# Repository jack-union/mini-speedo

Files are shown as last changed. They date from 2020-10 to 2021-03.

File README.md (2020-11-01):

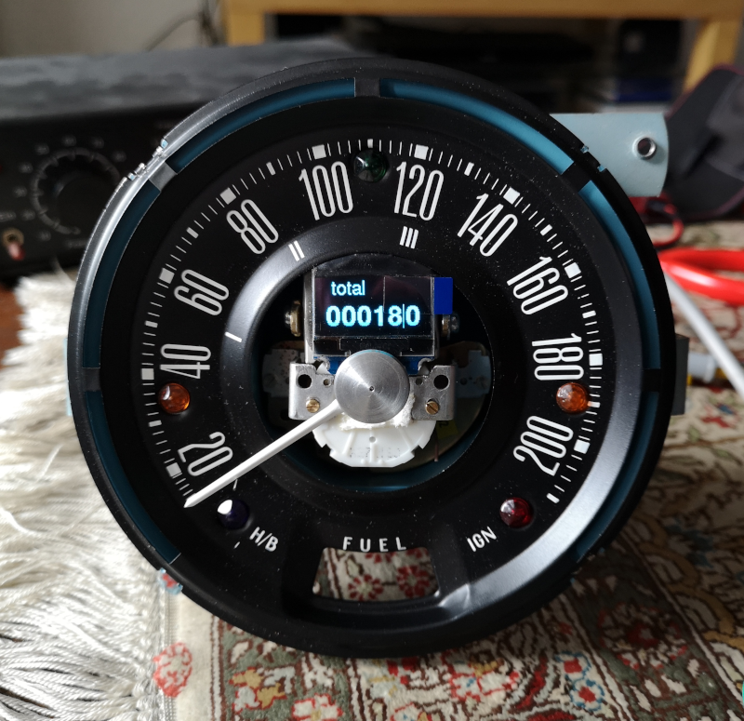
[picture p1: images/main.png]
mainimage


# mini-speedo
Electronic Speedo for classic minis

Using an Arduino Nano v3, a SSD1306 0,96" 128x64 display and a GM X27.168 stepper motor.

Featuring a multifunction display for:
* total distance
* trip distance
* digital speed
* lambda (AFR)
* oil temperature
* oil pressure
* voltage
* water temperature
* external temperature
* rpm

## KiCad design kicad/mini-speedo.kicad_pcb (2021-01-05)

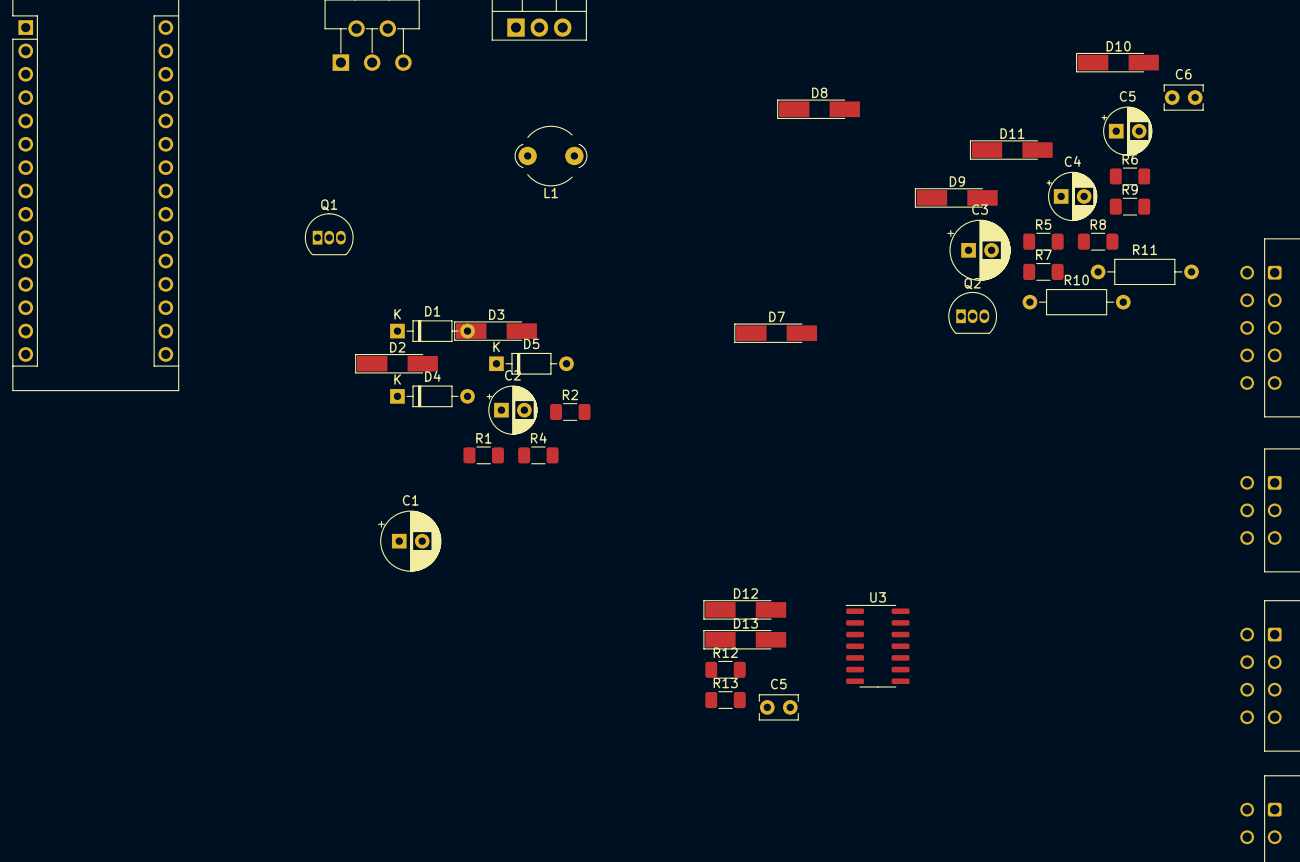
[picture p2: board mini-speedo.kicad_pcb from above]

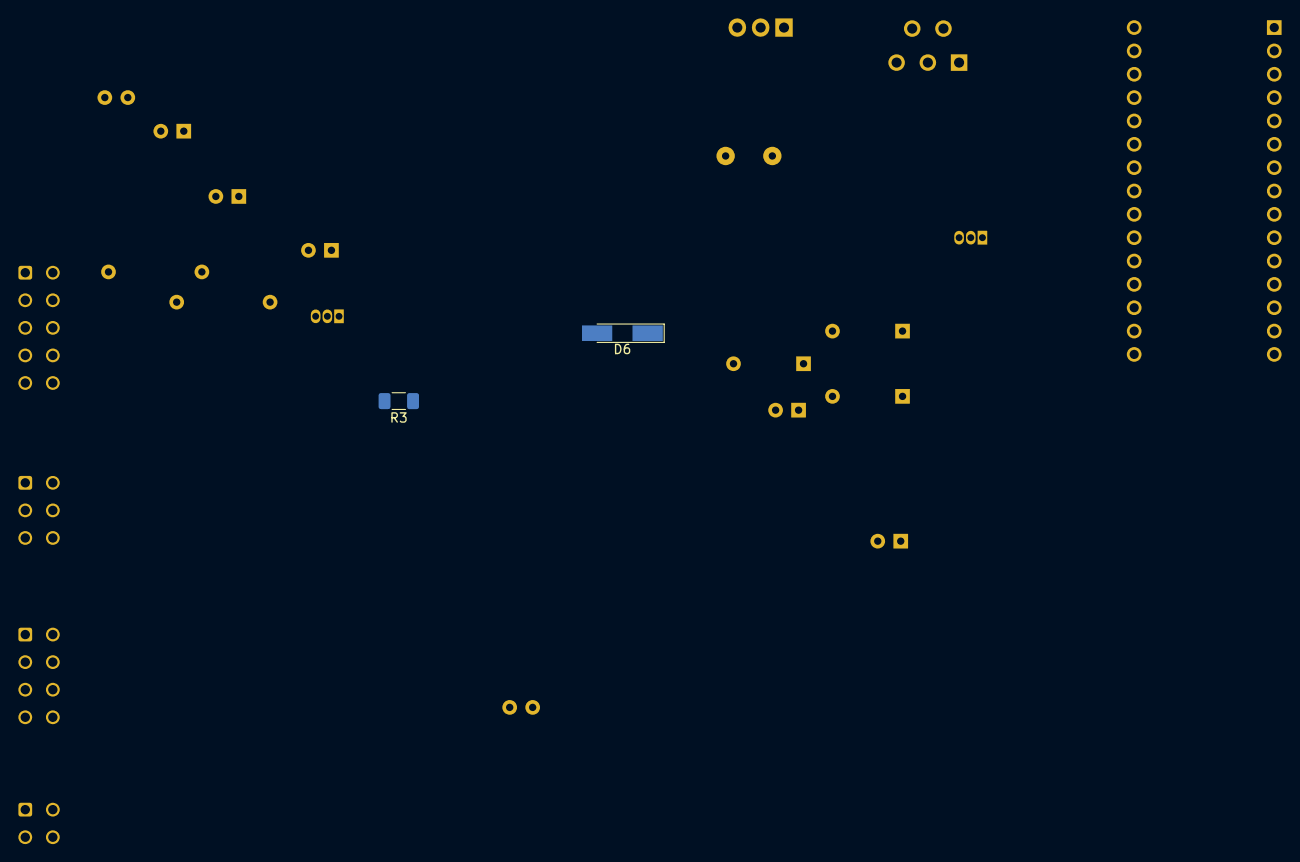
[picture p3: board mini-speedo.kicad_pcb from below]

Board: 2 copper layers, 44 parts (2 on the bottom side), 34 nets, no tracks yet.

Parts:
A1: Arduino; Arduino_Nano
C1, C3: 47uF; CP_Radial_D6.3mm_P2.50mm
C2, C4: 33uF; CP_Radial_D5.0mm_P2.50mm
C5: 10uF; CP_Radial_D5.0mm_P2.50mm
C5#2: 10nF; C_Rect_L4.0mm_W2.5mm_P2.50mm
C6: 33nF; C_Rect_L4.0mm_W2.5mm_P2.50mm
D1: D_Schottky; D_DO-35_SOD27_P7.62mm_Horizontal
D2, D3, D6, D7, D8, D9, D10, D11, D12, D13: 4.7V; D_MiniMELF_Handsoldering
D4, D5: 1N4148; D_DO-35_SOD27_P7.62mm_Horizontal
J1: Conn_01x06; Molex_Micro-Fit_3.0_43045-0600_2x03_P3.00mm_Horizontal
J2: Conn_01x08; Molex_Micro-Fit_3.0_43045-0800_2x04_P3.00mm_Horizontal
J3: Conn_01x10; Molex_Micro-Fit_3.0_43045-1000_2x05_P3.00mm_Horizontal
J4: Conn_01x04; Molex_Micro-Fit_3.0_43045-0400_2x02_P3.00mm_Horizontal
L1: 33uH; LairdTech_28C0236-0JW-10
Q1, Q2: BC546; TO-92_Inline
R1, R2, R3, R4, R6, R7, R8, R13: 10k; R_1206_3216Metric_Pad1.30x1.75mm_HandSolder
R5: 30k; R_1206_3216Metric_Pad1.30x1.75mm_HandSolder
R9: 1k; R_1206_3216Metric_Pad1.30x1.75mm_HandSolder
R10: 100; R_Axial_DIN0207_L6.3mm_D2.5mm_P10.16mm_Horizontal
R11: 470; R_Axial_DIN0207_L6.3mm_D2.5mm_P10.16mm_Horizontal
R12: 15k; R_1206_3216Metric_Pad1.30x1.75mm_HandSolder
U1: LM2596T-5; TO-220-5_P3.4x3.7mm_StaggerOdd_Lead3.8mm_Vertical
U2: LM7810_TO220; TO-220-3_Vertical
U3: 74HC14; SO-14_3.9x8.65mm_P1.27mm

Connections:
GND: A1.4, A1.29, C1.2, C2.2, C3.2, C4.2, C5.2, C5#2.2, C6.2, D1.2, D2.2, D3.2, D6.2, D7.2, D8.2, D9.2, D10.2, D11.2, D13.2, J1.6, J2.8, J3.2, J4.4, Q1.3, Q2.3, R6.1, R7.1, R13.1, U1.3, U2.2, U3.7
unnamed: A1.5, D8.1, R9.1
unnamed: A1.6, U3.2
unnamed: A1.7, J2.1
unnamed: A1.8, J2.2
unnamed: A1.9, J2.3
unnamed: A1.10, J2.4
unnamed: A1.13, D4.2
unnamed: A1.14, D2.1, R4.1
unnamed: A1.15, D5.1
unnamed: A1.16, R3.1
unnamed: A1.19, J3.3
unnamed: A1.20, D11.1, J3.5, R11.1
unnamed: A1.21, D10.1, J3.6, R10.1
unnamed: A1.22, D9.1, J3.7
unnamed: A1.23, J2.6
unnamed: A1.24, J2.7
unnamed: A1.25, C6.1, D7.1, R7.2, R8.1
unnamed: A1.26, C5.1, D6.1, R5.1, R6.2
unnamed: A1.27, C2.1, D12.1, J2.5, J3.1, L1.1, R10.2, R11.2, U1.4, U3.14
unnamed: C1.1, J1.1, U1.1
unnamed: C3.1, J1.2, J4.2, R1.2, R4.2, R5.2, U2.1
unnamed: C4.1, J1.3, U2.3
unnamed: C5#2.1, D12.2, D13.1, R12.1, R13.2
unnamed: D1.1, L1.2, U1.2
unnamed: D3.1, D5.2, R2.1, U1.5
unnamed: D4.1, J1.4
unnamed: J1.5, Q2.1
unnamed: J3.4, R8.2
unnamed: J4.1, R12.2
unnamed: J4.3, R9.2
unnamed: Q1.1, R2.2
unnamed: Q1.2, R1.1
unnamed: Q2.2, R3.2

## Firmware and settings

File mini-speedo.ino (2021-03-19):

/*
  Speedo with multifunction display

  Discussed here:
  https://www.mini-forum.de/forum/thread/95593-elektronischer-mitteltacho/

  Inspired by: https://retromini.weebly.com/blog/arduino-speedometer#

  Complete rewrite, though.

  Uses an Arduino Nano, a X27 stepper motor and a 0,96" OLED SSD1306 display

  jack union, 2020.

*/

#define MINI_SPEEDO_VERSION "Speedo v0.7"

//----Libraries to Include--------
#include <Arduino.h>
#include <Wire.h>
// edited in clib/u8g2.h
//#define U8G2_WITH_CLIP_WINDOW_SUPPORT
//#define U8G2_WITH_FONT_ROTATION
//#define U8G2_WITH_UNICODE
#include "SwitecX25.h"
#include <AltSoftSerial.h>
#include <EEPROMex.h>
#include <OneWire.h>
#include <U8g2lib.h>
#include <avr/wdt.h>
#define REQUIRESNEW false
#define REQUIRESALARMS false
#include <DallasTemperature.h>
//----End Libraries--------------

//----Define PIN Settings----------
#define INPUT_SPEED 2   // Interruptable PIN on Nano
#define INPUT_RPM 3     // Interruptable PIN on Nano
#define STEPPIN_1 4     // back view top right pin
#define STEPPIN_2 5     // back view bottom right pin
#define STEPPIN_3 6     // back view bottom left pin
#define STEPPIN_4 7     // back view top left pin
#define SERIAL_RX 8     // D8 lambda digital serial input
#define SERIAL_TX 9     // D9 lambda digital serial input
#define INPUT_BUTTON 10 // brake light test button
#define INPUT_POWER 11  // Power sense pin
#define OUTPUT_POWER 12 // Power off pin
#define OUTPUT_WARN 13  // D13 warn light out

#define INPUT_OUTSIDETEMP A0
#define INPUT_OILTEMP A1
#define INPUT_OILPRESS A2
#define INPUT_LAMBDA A3
// A4: SDA
// A5: SCL
#define INPUT_WATERTEMP A6
#define INPUT_VOLTAGE A7
//----End Define PIN Settings------

//----Define Lambda sensor input----
//#define LAMBDA_DIGITAL true //RX and TX serial pins
#define LAMBDA_DIGITAL false // analog 5V input
//----End Define Lambda sensor input----

//----Define warning limits----
#define WARN_MAX_OILTEMP 120   // 120° Celsius
#define WARN_MIN_OILPRESS 100  // 1 bar pressure
#define WARN_MIN_VOLTAGE 118   // 11.8 Volts
#define WARN_MAX_VOLTAGE 154   // 15.4 Volts
#define WARN_MAX_WATERTEMP 100 // 100° Celsius
#define WARN_MIN_OUTSIDETEMP 2 // 2° Celsius
//----End Define warning limits----

//----Define OLED Display Settings----
#define SCREEN_WIDTH 128 // OLED display width, in pixels
#define SCREEN_HEIGHT 64 // OLED display height, in pixels
//-----End OLED Display Settings------

//----Define other constants-------
#define SPEED_IMP_PER_REV 6 // impulses per revolution
#define IMP_PER_KM 800      // "Wegstrecke", impulses per 1000m
#define RPM_IMP_PER_REV 2   // SPI/Distributor, set to 1 for MPI
#define UPDATE_INTERVAL 100 // milliseconds speedo update rate
#define TEMP_EVERY_LOOPS 10 // every 10 loops update Dallas temperature sensor
//----End Define other constants---

//----Define sensor constants-------
#define ANALOGSAMPLES 5
#define MINITEMP_T0 303     // 303 Kelvin = 30° Celsius
#define MINITEMP_R0 833     // 833 Ohm at 303 Kelvin
#define MINITEMP_B 3540     // beta constant for Steinhart Hart
#define RACIMEXTEMP_T0 318  // 318 Kelvin = 45° Celsius
#define RACIMEXTEMP_R0 1240 // 1240 Ohm at 318 Kelvin
#define RACIMEXTEMP_B 3850  // beta constant for Steinhart Hart
#define OILTEMP_PULLUP 470  // 470 Ohm to 5V
#define WATERTEMP_PULLUP 61 // Resistance of water temp instrument
#define OILPRESS_PULLUP 100 // 100 Ohm to 5V
#define NODATA 65535        // max uint16 when no data
#define TEMPTOOHIGH 65534   // max uint16 -1 when reading too high
//----End Define sensor constants---

//----Stepper settings and object----
// standard X25.168 range 315 degrees at 1/3 degree steps
#define STEPS 248 * 3
// speedo type
#define SPEEDO_RANGE 210 // cooper with 210kph full range
#define SWEEP_AT_START 1
//----End Stepper settings and object----

//----Display modes----
#define TRIP 0
#define SPEED 1
#define LAMBDA 2
#define OIL_TEMP 3
#define OIL_PRESS 4
#define WATER_TEMP 5
#define VOLT 6
#define OUTSIDE 7
#define RPM 8
#define MINI 9

#define MODEMAX 9
//----End Display modes----

//----Display mode names----
const char *displayNames[] = {
    "trip",  "speed", "lambda",  "oil temp", "oil press",
    "water", "volt",  "outside", "rpm",
    "" // no text in logo mode
};
//----End Display mode names----

//----Define Display settings----
#define X_OFFSET 10
//----End Define Display settings----

//----EERPOM positions----
#define EE_TOKEN_POS 0
#define EE_TOKEN_PATTERN 170 // 10101010
#define EE_TOTAL_POS 1
#define EE_TRIP_POS 5
//----End EERPOM positions----

//----Objects----
// 1,3" SH1106 display
// U8G2_SH1106_128X64_NONAME_2_HW_I2C display(U8G2_R0);
// 0,96" SSD1306 display
U8G2_SSD1306_128X64_NONAME_2_HW_I2C bigDisplay(U8G2_R2);
// 0,96" SSD1306 additional display
U8G2_SSD1306_128X64_NONAME_2_HW_I2C smallDisplay(U8G2_R0);

// create the motor object with the maximum steps allowed
SwitecX25 stepper(STEPS, STEPPIN_1, STEPPIN_2, STEPPIN_3, STEPPIN_4);

// Serial input port
AltSoftSerial altSerial;

// External temperature
OneWire oneWire(INPUT_OUTSIDETEMP);
DallasTemperature outsideSensor(&oneWire);
DeviceAddress dallasDeviceAddress;
//----End Objects----

//-----Variables----------------------
uint32_t total = 0;       // total distance in decimeters
uint32_t trip = 0;        // trip distance in decimeters
uint16_t speed = 0;       // speed in kph
uint16_t lambda = 0;      // lambda factor *100
uint16_t oiltemp = 0;     // temperature in °C
uint16_t oilpress = 0;    // oil pressure in bar *100
uint16_t voltage = 0;     // main voltage in volt *10
uint16_t watertemp = 0;   // temperature in °C
uint16_t outsidetemp = 0; // temperature in °C *10
uint16_t rpm = 0;         // revolutions per minute

bool warningOiltemp = false;
bool warningOilpress = true; // probably no oil pressure at startup
bool warningVoltage = false;
bool warningWatertemp = false;
bool warningOutsidetemp = true; // no real startvalue for TEMP_EVERY_LOOPS

#define ROLLOVER 1000000000 // 100000km in decimeter
byte displayMode = TRIP;    // Startup setting
bool buttonState = HIGH;
bool buttonBeforeState = HIGH;
unsigned long timePressed = 0;
unsigned long displayUpdatedAt = 0;
bool displayChanged = false;
byte loops = 0;

#define ZEROTIME 1000 // no new interrupt pulses for max ms
volatile unsigned long rpmCount = 0;
volatile unsigned long rpmEvent = 0;
unsigned long rpmLastEvent = 0;
volatile unsigned long speedCount = 0;
volatile unsigned long speedEvent = 0;
unsigned long speedLastEvent = 0;

//----End Variables-------------------

//-----Start-up code run once---------
void setup(void) {
  MCUSR = 0;     // clear status register
  wdt_disable(); // watchdog disable

  Serial.begin(115200);
  altSerial.begin(115200);
  Serial.println(F(MINI_SPEEDO_VERSION));

  pinMode(INPUT_SPEED, INPUT_PULLUP);
  pinMode(INPUT_RPM, INPUT_PULLUP);
  pinMode(INPUT_BUTTON, INPUT_PULLUP);
  pinMode(INPUT_POWER, INPUT); // power sense pin
  pinMode(OUTPUT_POWER, OUTPUT);
  digitalWrite(OUTPUT_POWER, LOW); // power on
  pinMode(OUTPUT_WARN, OUTPUT);
  digitalWrite(OUTPUT_WARN, LOW); // warning off

  initOutsideSensor();
  initDisplays();
  delay(1000);
  reset_stepper();

  EEPROM.setMemPool(0, EEPROMSizeNano); // set memory size
  load_from_eeprom();

  attachInterrupt(digitalPinToInterrupt(INPUT_SPEED), interrupt_speed, RISING);
  attachInterrupt(digitalPinToInterrupt(INPUT_RPM), interrupt_rpm, RISING);

  Serial.println(F("Setup done."));
}
//------End Start-up code-------------

//------Start of Loop-----------------
void loop() {
  // check button status
  do_button();

  // display and data refresh every (UPDATE_INTERVAL) milliseconds
  if ((millis() - displayUpdatedAt) > UPDATE_INTERVAL) {
    gather_data();
    update_speed();
    update_rpm();
    check_warnings();
    do_display();
    do_stepper();
    displayUpdatedAt = millis();
    loops = loops + 1;
  }

  // refresh data from Dallas sensor less often
  if (loops == TEMP_EVERY_LOOPS) {
    outsidetemp = int(outsideSensor.getTempCByIndex(0) * 10);
    outsideSensor.requestTemperatures(); // request value for next run
    loops = 0;
  }

  // move stepper towards target position
  stepper.update();

  // switch power supply off and save to eeprom
  // when power goes down
  sense_power_off();
}
//-------End of Loop------------------

//-------Start interrupt handling-----
void interrupt_speed() {
  speedCount++;
  speedEvent = millis();
}

void interrupt_rpm() {
  rpmCount++;
  rpmEvent = millis();
}
//-------End interrupt handling-----

//-------Start of Functions-----------
void do_button() {
  buttonState = digitalRead(INPUT_BUTTON);
  if (buttonState == LOW) {
    if (buttonBeforeState == HIGH) { // press started
      timePressed = millis();
      buttonBeforeState = LOW;
    } else {                               // still holding LOW
      if (millis() - timePressed > 1000) { // one second hold
        if (displayMode == TRIP) {
          trip = 0; // reset trip
        }
      }
    }
  } else {                          // buttonState HIGH
    if (buttonBeforeState == LOW) { // just released
      if ((millis() - timePressed > 50) and
          (millis() - timePressed < 1000)) { // short press ended
        increment_display();
        displayChanged = true;
      }
      buttonBeforeState = HIGH;
    }
  }
}

void initOutsideSensor() {
  outsideSensor.begin();
  outsideSensor.getAddress(dallasDeviceAddress, 0);
  outsideSensor.setResolution(dallasDeviceAddress,
                              9);            // less resolution, faster reading
  outsideSensor.setWaitForConversion(false); // async reading
  outsideSensor.requestTemperatures();       // start first request
}

void sense_power_off() {
  if (digitalRead(INPUT_POWER) == LOW) {
    save_to_eeprom();
    stepper.setPosition(0);
    stepper.updateBlocking();
    bigDisplay.firstPage();
    do {
      draw_goodbye();
    } while (bigDisplay.nextPage());
    delay(2000);
    digitalWrite(OUTPUT_POWER, HIGH);
    stop();
  }
}

void load_from_eeprom() {
  if (EEPROM.readByte(EE_TOKEN_POS) == EE_TOKEN_PATTERN) { // found pattern?
    total = EEPROM.readLong(EE_TOTAL_POS);
    trip = EEPROM.readLong(EE_TRIP_POS);
  } else { // first start, save zero values
    EEPROM.writeByte(EE_TOKEN_POS, EE_TOKEN_PATTERN);
    EEPROM.writeLong(EE_TOTAL_POS, 0);
    EEPROM.writeLong(EE_TRIP_POS, 0);
  }
}

void save_to_eeprom() {
  // When? At least at stop.
  // The EEPROM memory has a specified life of 100,000 write/erase cycles
  // An EEPROM write takes 3.3 ms to complete.
  EEPROM.updateLong(EE_TOTAL_POS, total);
  EEPROM.updateLong(EE_TRIP_POS, trip);
}

void stop() {
  delay(1000);           // wait a second
  wdt_enable(WDTO_15MS); // enable watchdog
  for (;;)
    ; // are we still there? wait for watchdog to reset us.
}

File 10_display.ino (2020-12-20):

/*
   display functions

*/
#define SMALL_FONT u8g2_font_logisoso18_tf
#define LARGE_FONT u8g2_font_logisoso24_tn

void initDisplays() {
  //bigDisplay.setI2CAddress(0x78); //0x3c * 2, default
  bigDisplay.setI2CAddress(0x7a); //0x3d * 2
  bigDisplay.begin();
  bigDisplay.setDrawColor(1);
  bigDisplay.setFontMode(0);
  smallDisplay.setI2CAddress(0x78); //0x3c * 2, default
  //smallDisplay.setI2CAddress(0x7a); //0x3d * 2
  smallDisplay.begin();
  smallDisplay.setDrawColor(1);
  smallDisplay.setFontMode(0);

  bigDisplay.firstPage();
  do {
    draw_logo();
  } while ( bigDisplay.nextPage() );

  smallDisplay.firstPage();
  do {
    smallDisplay.setFont(SMALL_FONT);
    smallDisplay.setCursor(0, 60);
    smallDisplay.println(F(MINI_SPEEDO_VERSION));
  } while ( smallDisplay.nextPage() );
}

void do_display() {
  if (displayMode != MINI) {
    if (displayChanged) {
      scroll_mode(displayNames[displayMode]);
      displayChanged = false;
    }
  }

  bigDisplay.firstPage();
  do {
    draw_mode(displayNames[displayMode]);
    switch (displayMode) {
      case TRIP:
        draw_trip(trip / 1000); //decimeters to 100m
        break;
      case SPEED:
        draw_speed(speed);
        break;
      case LAMBDA:
        draw_lambda(lambda);
        break;
      case OIL_TEMP:
        draw_oil_temp(oiltemp);
        break;
      case OIL_PRESS:
        draw_oil_press(oilpress);
        break;
      case VOLT:
        draw_voltage(voltage);
        break;
      case WATER_TEMP:
        draw_water_temp(watertemp);
        break;
      case OUTSIDE:
        draw_outside_temp(outsidetemp);
        break;
      case RPM:
        draw_rpm(rpm);
        break;
      case MINI:
        draw_logo();
        break;
    }
  } while ( bigDisplay.nextPage() );

  smallDisplay.firstPage();
  do {
    draw_odo(total / 1000); //decimeters to 100m
  } while ( smallDisplay.nextPage() );
}

void increment_display () {
  if (displayMode < MODEMAX) {
    displayMode++;
  } else {
    displayMode = 0;
  }
}

void scroll_mode(String param) {
  int len;
  String prt;

  bigDisplay.setFont(SMALL_FONT);

  for (int row = 55; row > X_OFFSET; row = row - 6 ) {
    bigDisplay.firstPage();
    do {
      bigDisplay.setCursor(row, 20);
      len = ((128 - row) / 10) - 2;
      prt = param;
      prt.remove(len);
      bigDisplay.print(prt);
    } while ( bigDisplay.nextPage() );
    delay(1);
  }
}

void draw_mode(String param) {
  bigDisplay.setFont(SMALL_FONT);
  bigDisplay.setCursor(X_OFFSET, 20);
  bigDisplay.print(param);
}

void draw_odo(uint32_t readout) {
  char data[8] = "";
  sprintf(data, "%07d", readout);

  smallDisplay.setFont(LARGE_FONT);
  smallDisplay.setCursor(3, 60);
  smallDisplay.print(data[1]);
  smallDisplay.setCursor(23, 60);
  smallDisplay.print(data[2]);
  smallDisplay.setCursor(43, 60);
  smallDisplay.print(data[3]);
  smallDisplay.setCursor(63, 60);
  smallDisplay.print(data[4]);
  smallDisplay.setCursor(83, 60);
  smallDisplay.print(data[5]);

  smallDisplay.drawLine(101, 34, 101, 63);

  smallDisplay.setCursor(106, 60);
  smallDisplay.println(data[6]);
}

void draw_trip(uint32_t readout) {
  char data[8] = "";
  sprintf(data, "%7d", readout);

  bigDisplay.setFont(LARGE_FONT);
  bigDisplay.setCursor(3, 60);
  bigDisplay.print(data[1]);
  bigDisplay.setCursor(23, 60);
  bigDisplay.print(data[2]);
  bigDisplay.setCursor(43, 60);
  bigDisplay.print(data[3]);
  bigDisplay.setCursor(63, 60);
  bigDisplay.print(data[4]);
  bigDisplay.setCursor(83, 60);
  bigDisplay.print(data[5]);

  bigDisplay.drawLine(101, 34, 101, 63);

  bigDisplay.setCursor(106, 60);
  bigDisplay.println(data[6]);
}

void draw_speed(uint16_t readout) {
  char data[4] = "";
  sprintf(data, "%3d", readout);

  bigDisplay.setFont(LARGE_FONT);
  bigDisplay.setCursor(20, 60);
  bigDisplay.println(data);

  bigDisplay.setFont(SMALL_FONT);
  bigDisplay.setCursor(75, 60);
  bigDisplay.println(F("km/h"));
}

void draw_lambda(uint16_t readout) {
  char data[4] = "";
  sprintf(data, "%03d", readout);

  bigDisplay.setFont(LARGE_FONT);
  bigDisplay.setCursor(10, 60);
  bigDisplay.print(data[0]);
  bigDisplay.print(".");
  bigDisplay.print(data[1]);
  bigDisplay.print(data[2]);

  bigDisplay.setFont(SMALL_FONT);
  bigDisplay.setCursor(80, 60);
  if (readout < 100 ) {
    bigDisplay.println(F("rich"));
  } else {
    bigDisplay.println(F("lean"));
  }
}

void draw_oil_temp(uint16_t readout) {
  char data[4] = "";
  sprintf(data, "%3d", readout);

  bigDisplay.setFont(LARGE_FONT);
  bigDisplay.setCursor(15, 60);

  if ( readout == NODATA ) {
    bigDisplay.println(F("---"));
  } else if ( readout == TEMPTOOHIGH ) {
    bigDisplay.println(F("+++"));
  } else {
    bigDisplay.println(data);
  }

  bigDisplay.setFont(SMALL_FONT);
  bigDisplay.setCursor(85, 60);
  bigDisplay.println(char(0xb0)); //ASCII "degrees" symbol
  bigDisplay.println(F("C"));

  if ( warningOiltemp ) {
    draw_warning();
  }
}

void draw_oil_press(uint16_t readout) {
  char data[4] = "";
  bigDisplay.setFont(LARGE_FONT);
  bigDisplay.setCursor(15, 60);

  if ( readout == NODATA ) {
    bigDisplay.print("-.--");
  } else {
    sprintf(data, "%03d", readout);

    bigDisplay.print(data[0]);
    bigDisplay.print(".");
    bigDisplay.print(data[1]);
    bigDisplay.print(data[2]);
  }

  bigDisplay.setFont(SMALL_FONT);
  bigDisplay.setCursor(85, 60);
  bigDisplay.println(F("bar"));

  if ( warningOilpress ) {
    draw_warning();
  }
}

void draw_voltage(uint16_t readout) {
  char data[4] = "";
  sprintf(data, "%3d", readout);

  bigDisplay.setFont(LARGE_FONT);
  bigDisplay.setCursor(10, 60);
  bigDisplay.print(data[0]);
  bigDisplay.print(data[1]);
  bigDisplay.print(".");
  bigDisplay.print(data[2]);

  bigDisplay.setFont(SMALL_FONT);
  bigDisplay.setCursor(80, 60);
  bigDisplay.println(F("volt"));

  if ( warningVoltage ) {
    draw_warning();
  }
}

void draw_water_temp(uint16_t readout) {
  char data[4] = "";
  sprintf(data, "%3d", readout);

  bigDisplay.setFont(LARGE_FONT);
  bigDisplay.setCursor(15, 60);

  if ( readout == NODATA ) {
    bigDisplay.println(F("---"));
  } else if ( readout == TEMPTOOHIGH ) {
    bigDisplay.println(F("+++"));
  } else {
    bigDisplay.println(data);
  }

  bigDisplay.setFont(SMALL_FONT);
  bigDisplay.setCursor(85, 60);
  bigDisplay.println(char(0xb0)); //ASCII "degrees" symbol
  bigDisplay.println(F("C"));

  if ( warningWatertemp ) {
    draw_warning();
  }
}

void draw_outside_temp(int16_t readout) {
  char data[5] = "";
  sprintf(data, "% 4d", readout);

  bigDisplay.setFont(LARGE_FONT);
  bigDisplay.setCursor(10, 60);
  bigDisplay.print(data[0]);
  bigDisplay.print(data[1]);
  bigDisplay.print(data[2]);
  bigDisplay.print(".");
  bigDisplay.print(data[3]);

  bigDisplay.setFont(SMALL_FONT);
  bigDisplay.setCursor(85, 60);
  bigDisplay.println(char(0xb0)); //ASCII "degrees" symbol
  bigDisplay.println(F("C"));
  if ( warningOutsidetemp ) {
    draw_warning();
  }
}
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

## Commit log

2020-08-24 Renamed file due to Arduino IDE
2020-08-24 input definitions cleanup, created interrupt handling
2020-08-24 little cleanup, stepper code reactivated
2020-08-27 interrupt handling, rpm and speed data handling started
2020-08-27 Update stepper in main loop, asynchronously.
2020-08-28 distances in meters, adapted display accordingly. corrected distance calculations. explicitly stated units. added rollover code for 100000km display.
    [mini-speedo.ino]
2020-08-28 Speedo stepper code, first shot.
2020-08-29 kicad schematics added, first incomplete version
    [mini-speedo.kicad_pcb, mini-speedo.sch]
2020-08-30 explained stepper pins better
2020-08-30 set max stepper position according to speedo scale
2020-08-30 Nicer fonts, updates all display functions. Fine tuning max stepper travel.
2020-09-23 Further tests with kicad.
    [mini-speedo.kicad_pcb, mini-speedo.sch]
2020-09-23 used watchdog to reset Arduino when power is restored quickly.
    [mini-speedo.ino]
2020-09-24 pin assignment for serial lambda and warn output
2020-11-01 KiCad changes, first prototype
    [mini-speedo.sch]
2020-11-02 Analog value calculations for lambda and voltage
2020-11-09 set oil pressure warning from begin, so display doesn't switch at startup
    [mini-speedo.ino]
2020-11-14 Pin swaps for software serial
    [mini-speedo.ino]
2020-11-14 Upper limit for voltage reading
2020-11-14 Set warning output pin when warning is active
2020-11-14 Fixes goodbye drawing (u8g2 loop)
    [10_display.ino, mini-speedo.ino]
2020-11-14 Fine tuned stepper max position
2020-11-16 voltage and lambda demodata removed
2020-11-16 Digital sensor DS18B20 reading for outside temperature
2020-11-16 switched to leaner DS18B20_INT library
2020-12-05 Compute oil pressure
2020-12-05 print oil pressure as -.-- when sensor not connected
2020-12-05 use NODATA as marker for unavailable sensor data
2020-12-12 Added constants for analog sensors. Multiple runs for analog samples to smooth data.
2020-12-13 More constants for sensor readings
2020-12-13 disable digital temp sensor for the moment...
2020-12-13 Thermistor temperature floating point calculations and display updates.
2020-12-15 Little cleanups, reduce resolution for Dallas temperature sensor
2020-12-15 replaced several constants with #defines
    [mini-speedo.ino]
2020-12-15 switched inputs, removed altSoftSerial temporarily, included DallasTemperature
2020-12-15 Dallas temperature reading for outside temp. Changed to 0.5 degrees resolution.
2020-12-16 reduced memory footprint by using reduced small font.
2020-12-17 switched logo to van
2020-12-17 Added AltSerial dummy code for testing object memory footprint
2021-01-05 Schematics update, still not finished
    [mini-speedo.kicad_pcb, mini-speedo.sch]
